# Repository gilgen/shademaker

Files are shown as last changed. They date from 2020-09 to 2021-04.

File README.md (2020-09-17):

# Shademaker

An open source implementation of a stepper driven automated blind system.

## Required components
* Stepper motor (5:1 planetary geared)
* Arduino
* Hacked CNC shield
* 8825 stepper drivers
* Light sensor module
* Up/Down momentary switches
* On/Off toggle switch
* Relay
* 24v solenoid
* 8mm shaft couplers (no more than 16mm in diameter)
* 8mm rod
* 24v power supply

## WIP
desk

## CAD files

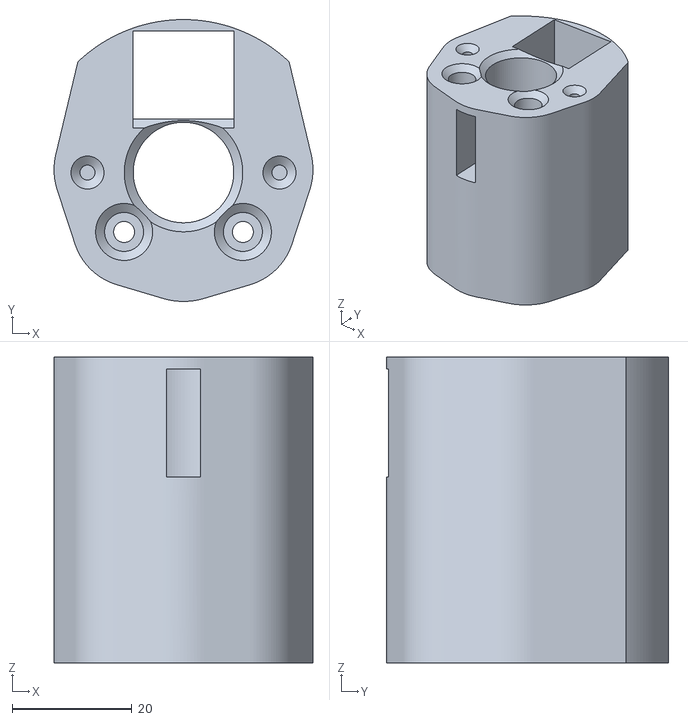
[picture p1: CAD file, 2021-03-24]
motor/stl/solenoid_holder.stl
43.2 x 47.0 x 51.0

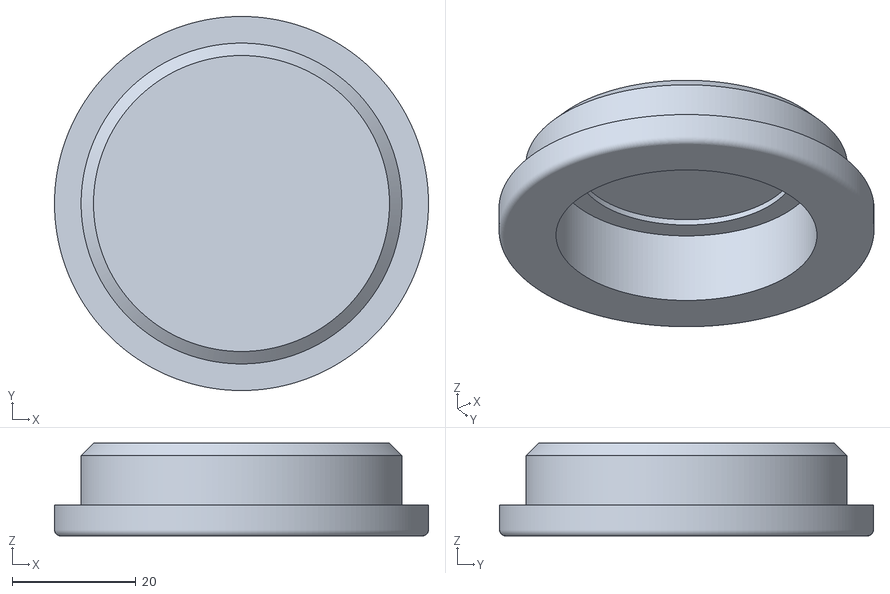
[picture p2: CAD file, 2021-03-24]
motor/stl/endcap.stl
60.3 x 60.3 x 15.0

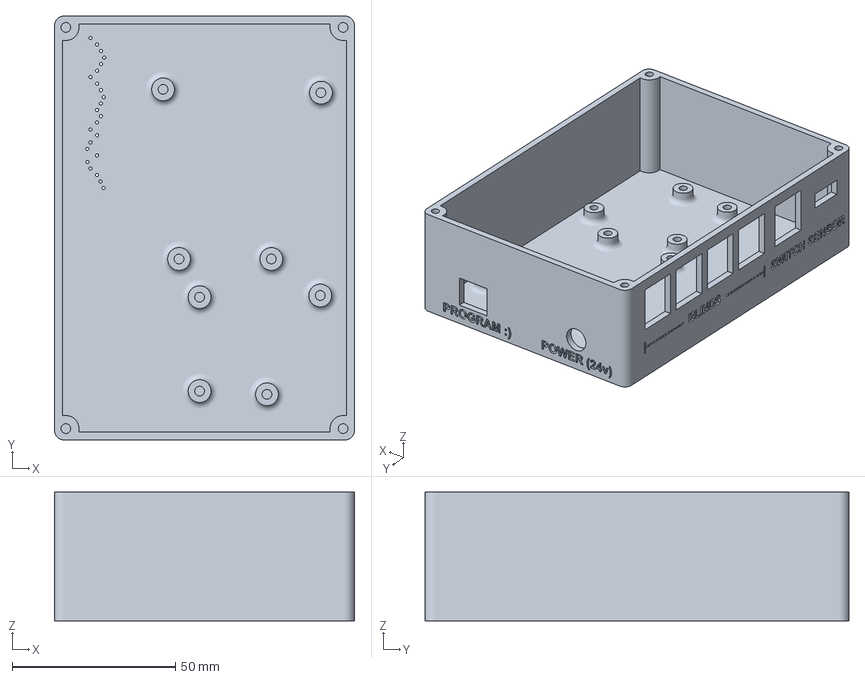
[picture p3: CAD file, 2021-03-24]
motor/stl/larger_enclosure_base.3mf
92.0 x 130.0 x 39.5 mm

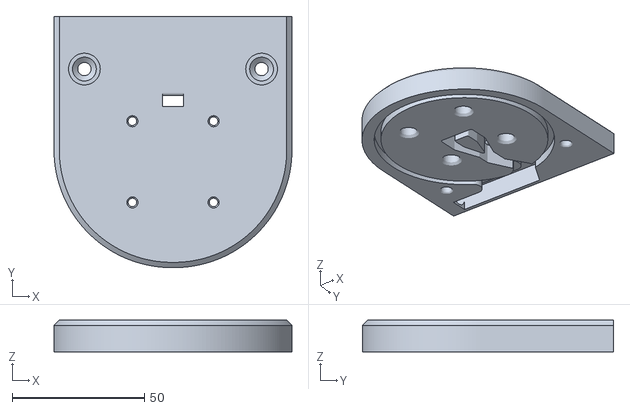
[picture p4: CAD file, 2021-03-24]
motor/stl/motor_mount.stl
90.0 x 95.0 x 12.0

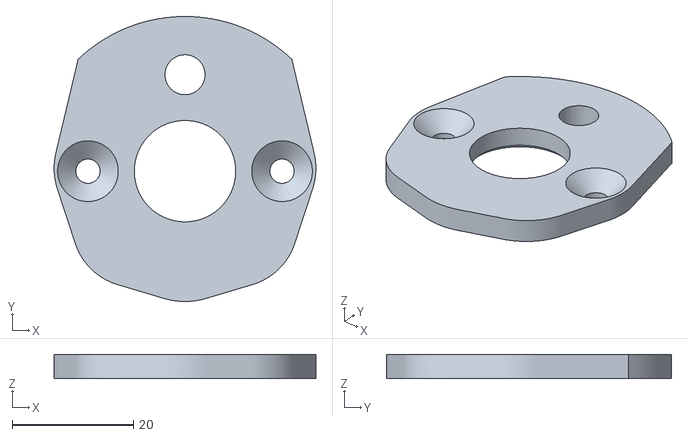
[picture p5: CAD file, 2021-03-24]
motor/stl/solenoid_plate.stl
43.2 x 47.0 x 4.00

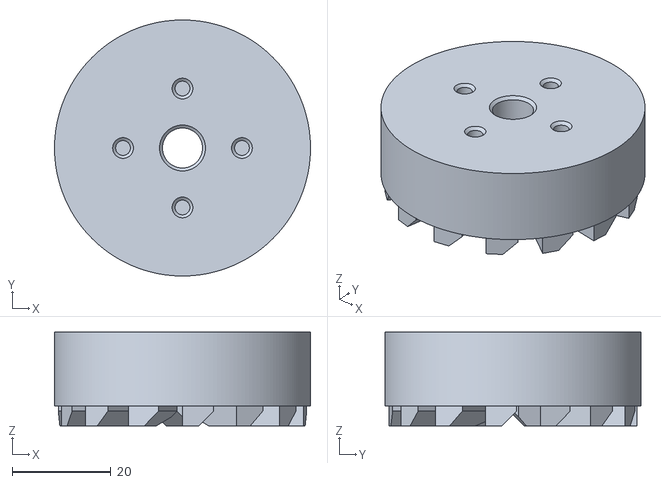
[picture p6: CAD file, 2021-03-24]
motor/stl/ratchet_gear.stl
51.9 x 51.9 x 19.0

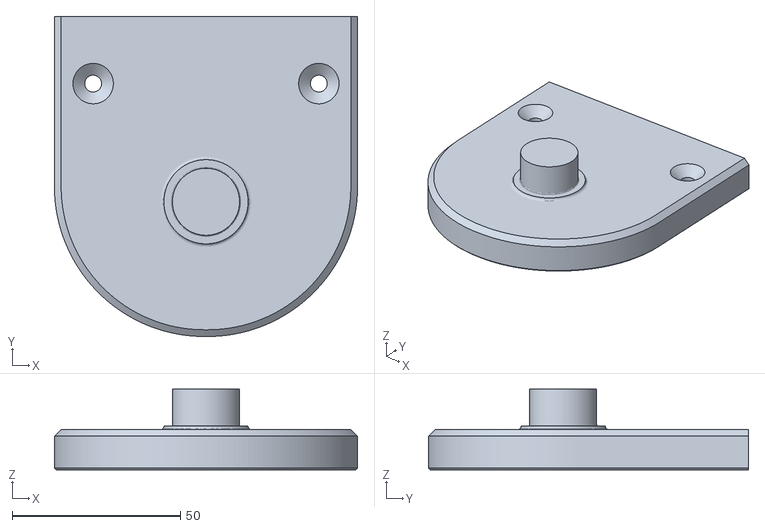
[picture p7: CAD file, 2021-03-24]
motor/stl/idler_mount.stl
90.0 x 95.0 x 24.0

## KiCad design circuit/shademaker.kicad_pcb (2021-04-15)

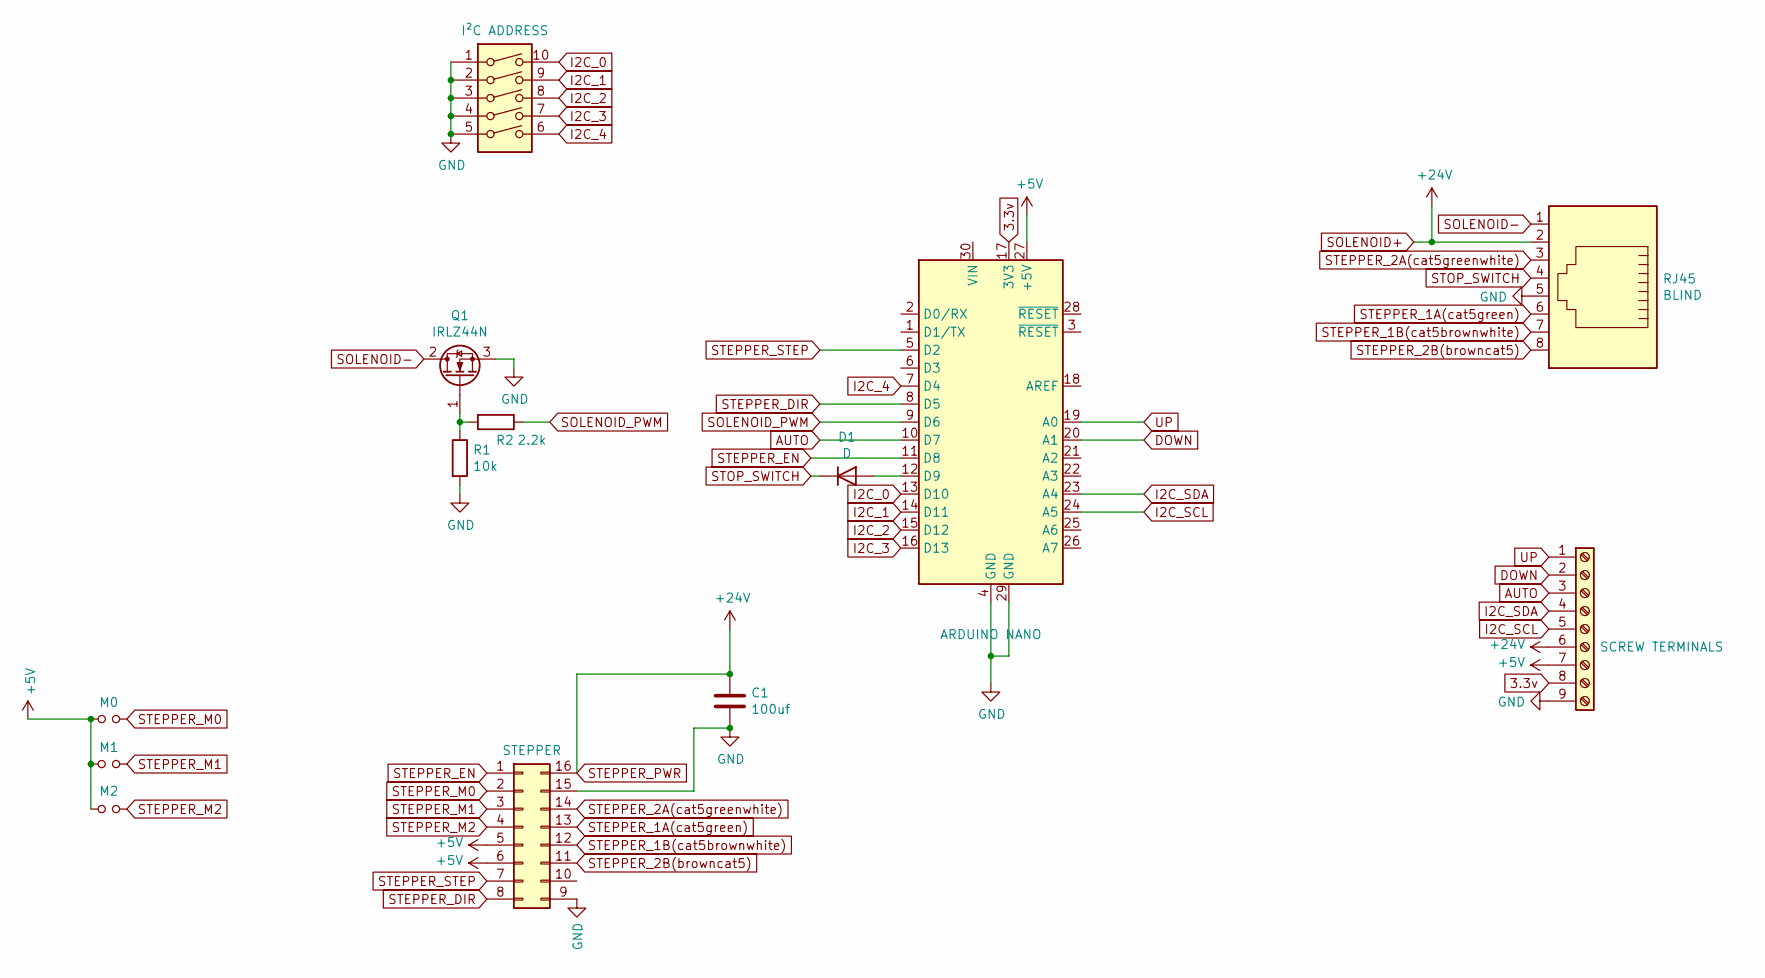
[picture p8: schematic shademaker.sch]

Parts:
ARDUINO1: ARDUINO NANO; Arduino_Nano
C1: 100uf; C_Radial_D10.0mm_H16.0mm_P5.00mm
D1: D; D_DO-15_P10.16mm_Horizontal
M1, M2: Jumper_NO_Small; TestPoint_2Pads_Pitch2.54mm_Drill0.8mm
MO1: M0; TestPoint_2Pads_Pitch2.54mm_Drill0.8mm
Q1: IRLZ44N; TO-220-3_Vertical
R1: 10k; R_Axial_DIN0207_L6.3mm_D2.5mm_P10.16mm_Horizontal
R2: 2.2k; R_Axial_DIN0207_L6.3mm_D2.5mm_P10.16mm_Horizontal
RJ45: BLIND; RJ45_Amphenol_54602-x08_Horizontal
SCREW1: SCREW TERMINALS; TerminalBlock_Phoenix_PT-1,5-9-3.5-H_1x09_P3.50mm_Horizontal
STEPPER1: STEPPER; Pololu_Breakout-16_15.2x20.3mm
SW1: I²C ADDRESS; SW_DIP_SPSTx05_Slide_6.7x14.26mm_W7.62mm_P2.54mm_LowProfile

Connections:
3.3v: ARDUINO1.17 (3V3), SCREW1.8
+5V: ARDUINO1.27 (+5V), M1.1, M2.1, MO1.1, SCREW1.7, STEPPER1.5, STEPPER1.6
AUTO: ARDUINO1.10 (D7), SCREW1.3
DOWN: ARDUINO1.20 (A1), SCREW1.2
GND: ARDUINO1.4 (GND), ARDUINO1.29 (GND), C1.2, Q1.3 (S), R1.2, RJ45.5, SCREW1.9, STEPPER1.9, STEPPER1.15, SW1.1, SW1.2, SW1.3, SW1.4, SW1.5
I2C_0: ARDUINO1.13 (D10), SW1.10
I2C_1: ARDUINO1.14 (D11), SW1.9
I2C_2: ARDUINO1.15 (D12), SW1.8
I2C_3: ARDUINO1.16 (D13), SW1.7
I2C_4: ARDUINO1.7 (D4), SW1.6
I2C_SCL: ARDUINO1.24 (A5), SCREW1.5
I2C_SDA: ARDUINO1.23 (A4), SCREW1.4
unnamed: ARDUINO1.12 (D9), D1.2 (A)
unnamed: Q1.1 (G), R1.1, R2.2
SOLENOID+: C1.1, RJ45.2, SCREW1.6, STEPPER1.16
SOLENOID-: Q1.2 (D), RJ45.1
SOLENOID_PWM: ARDUINO1.9 (D6), R2.1
STEPPER_1A(cat5green): RJ45.6, STEPPER1.13
STEPPER_1B(cat5brownwhite): RJ45.7, STEPPER1.12
STEPPER_2A(cat5greenwhite): RJ45.3, STEPPER1.14
STEPPER_2B(browncat5): RJ45.8, STEPPER1.11
STEPPER_DIR: ARDUINO1.8 (D5), STEPPER1.8
STEPPER_EN: ARDUINO1.11 (D8), STEPPER1.1
STEPPER_M0: MO1.2, STEPPER1.2
STEPPER_M1: M1.2, STEPPER1.3
STEPPER_M2: M2.2, STEPPER1.4
STEPPER_STEP: ARDUINO1.5 (D2), STEPPER1.7
STOP_SWITCH: D1.1 (K), RJ45.4
UP: ARDUINO1.19 (A0), SCREW1.1

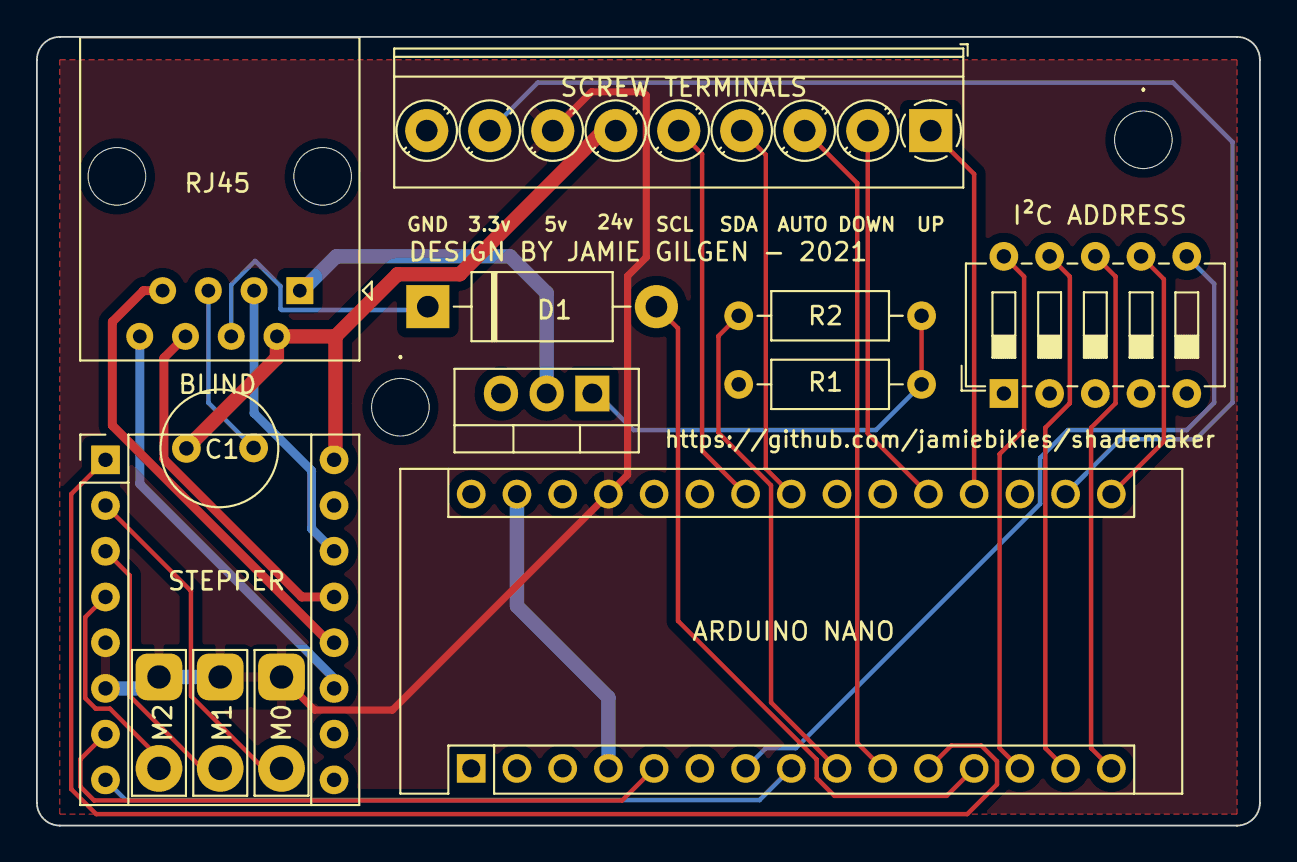
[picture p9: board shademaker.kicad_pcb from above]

Board: 2 copper layers, 67.9 x 43.8 mm, 15 parts (0 on the bottom side), 29 nets.

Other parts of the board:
., .#2: MountingHole_3.2mm_M3

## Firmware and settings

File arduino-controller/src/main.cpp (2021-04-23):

#include <AccelStepper.h>
#include <OneButton.h>
#include <Fsm.h>
#include <EEPROM.h>
#include <Wire.h>

// Forward declarations
boolean moveBlindsUpButtonActive();
boolean moveBlindsDownButtonActive();
boolean atTop();
boolean atBottom();
boolean autoModeEnabled();
boolean readyForAutoCmd();
boolean isBrightOutside();
boolean stopPinActive();
boolean atSetMidpointPosition();
boolean isValidCommand(int command);
int getI2CAddress();
void handleReceivedCommand();
long getDesiredBlindPosition();
void receiveI2CCommand(int numByets);
void i2cStateRequestHandler();
void setReceivedCommand(int command);
int getReceivedCommand();
void storeCurrentPositionAsBottom();
void setDesiredBlindPosition(long newPosition);
void homeStepper();
void moveBlinds(long longPosition);
void stopBlinds();
void initializeBottomPosition();
void initializePinIO();
void disableSolenoid();
void initializeSwitchHandlers();
void initializeStepper();
void initializeFSMTransitions();
void enableSolenoid();
void disableSolenoid();
void setCurrentPositionAsHome();
void setSolenoidLowPowerMode();
void runAutoModeRoutines();
void onStoppedStateEnter();
void onMovingStateEnter();
void onTransMovingToStoppedByMotorsAtTop();
void onTransStoppedToMovingByDownClick();
void onTransStoppedToMovingByUpClick();
void onTransStoppedToMovingByMoveToPosition();
void onTransMovingToMovingByMoveCommand();

#define DEBUG_MODE true

// Pin 0 not used
// Pin 1 not used
#define STEP_PIN    2
#define I2C_4       4
#define DIRECTION   5
#define SOLENOID    6
#define AUTO_MODE   7
#define ENABLE_PIN  8
#define STOP_PIN    9
#define I2C_0       10
#define I2C_1       11
#define I2C_2       12
#define I2C_3       13
#define UP_PIN      A0
#define DOWN_PIN    A1
#define TEMPERATURE A2
#define LIGHT       A3
#define I2C_SDA     A4
#define I2C_SCL     A5

// Stepper driver modules
#define DRV8825 0
#define TMC2209 1

// Should be one of the above driver modules
#define DRIVER_MODULE TMC2209

#if DRIVER_MODULE == DRV8825
  #define STEPS_PER_SHAFT_REVOLUTION 800L
  #define DIRECTION_PIN_INVERTED false
  #define STEP_PIN_INVERTED false
  #define ENABLE_PIN_INVERTED true
  #define SOLENOID_ENABLE_STEPPER_BUMP 250
#elif DRIVER_MODULE == TMC2209
  #define STEPS_PER_SHAFT_REVOLUTION 1600L
  #define DIRECTION_PIN_INVERTED true
  #define STEP_PIN_INVERTED false
  #define ENABLE_PIN_INVERTED true
  #define SOLENOID_ENABLE_STEPPER_BUMP 400
#else
  #error You need to select a DRIVER_MODULE
#endif

#define GEAR_RATIO 5.18181818L
#define AUTO_TRANSITION_INTERVAL (unsigned long)18000000 // 5 hours (or use 100000 for testing)
#define REVOLUTION (long)(STEPS_PER_SHAFT_REVOLUTION * GEAR_RATIO)
#define MAX_SPEED REVOLUTION * 0.4 // The UNO can do just over 4000 steps/s :'(
#define ACCELERATION MAX_SPEED * 1.8
#define SWITCHES_ACTIVE_LOW true
#define SWITCHES_USE_PULLUP true
#define BOTTOM_POSITION_ADDRESS 0
#define SLIP_CORRECTION 2 * REVOLUTION
#define SOLENOID_PWM_LEVEL 110
#define CYCLES_BEFORE_SOLENOID_LOW_POWER 30000L
#define HOMING_STATE_RETURN_VALUE 200

// I2C commands
#define STOP_COMMAND 101
#define DOWN_FOREVER_COMMAND 102
#define STORE_COMMAND 103
#define UP_FOREVER_COMMAND 104
#define FOREVER_POSITION 100*REVOLUTION
#define NOOP 200

// FSM events
#define AUTO_DOUBLE_CLICK   1
#define DOWN_CLICK          2
#define UP_CLICK            3
#define MOTORS_AT_TOP       5
#define STOP                6
#define MOVE_COMMAND        7

boolean isHoming = false;
unsigned long lastMoveAt = 0;
unsigned long startedAt;
long desiredBlindPosition;
long bottomPosition;
int loopCnt = 0;
int lastReceivedCommand = NOOP;

// Stepper
AccelStepper stepper = AccelStepper(AccelStepper::DRIVER, STEP_PIN, DIRECTION);

// Buttons
OneButton upSwitch = OneButton(UP_PIN, SWITCHES_ACTIVE_LOW, SWITCHES_USE_PULLUP);
OneButton downSwitch = OneButton(DOWN_PIN, SWITCHES_ACTIVE_LOW, SWITCHES_USE_PULLUP);
OneButton autoSwitch = OneButton(AUTO_MODE, SWITCHES_ACTIVE_LOW, SWITCHES_USE_PULLUP);

// FSM
State stoppedState(&onStoppedStateEnter, NULL, NULL);
State movingState(&onMovingStateEnter, NULL, NULL);
Fsm fsm(&stoppedState);

void setup() {
  Serial.begin(9600);
  Serial.print("Initializing\n");
  initializeBottomPosition();
  initializePinIO();
  disableSolenoid();  
  initializeStepper();
  Wire.begin(getI2CAddress());
  Wire.onReceive(receiveI2CCommand);
  Wire.onRequest(i2cStateRequestHandler);
  homeStepper();
  initializeSwitchHandlers();
  initializeFSMTransitions();
  fsm.run_machine();
  Serial.println("Done initialization");
  startedAt = millis();
}

void loop() {

  if (atTop() && getDesiredBlindPosition() <= 0) {
    fsm.trigger(MOTORS_AT_TOP);
  } else if (stepper.distanceToGo() == 0) {
    fsm.trigger(STOP);
  }

  handleReceivedCommand();

  // Only tick periodically to speed up the run loop. This
  // allows the motors to run a bit smoother
  // Uncomment if you're using a hardwired auto switch
  // if (loopCnt % 5000 == 0) {
  //   runAutoModeRoutines();
  // }

  if (loopCnt % 50 == 0) {
    // Tick the switches
    upSwitch.tick();
    downSwitch.tick();
    autoSwitch.tick();
  }

  // Run the steppers
  stepper.run();
  loopCnt++;
}

void initializePinIO() {
  pinMode(DIRECTION, OUTPUT);
  pinMode(STEP_PIN, OUTPUT);
  pinMode(STOP_PIN, INPUT_PULLUP);
  pinMode(ENABLE_PIN, OUTPUT);
  pinMode(SOLENOID, OUTPUT);
  pinMode(UP_PIN, INPUT_PULLUP);
  pinMode(DOWN_PIN, INPUT_PULLUP);
  pinMode(LIGHT, INPUT_PULLUP);
  pinMode(AUTO_MODE, INPUT_PULLUP);
  pinMode(I2C_0, INPUT_PULLUP);
  pinMode(I2C_1, INPUT_PULLUP);
  pinMode(I2C_2, INPUT_PULLUP);
  pinMode(I2C_3, INPUT_PULLUP);
  pinMode(I2C_4, INPUT_PULLUP);
}

void initializeFSMTransitions() {
  fsm.add_transition(&stoppedState, &movingState, DOWN_CLICK, &onTransStoppedToMovingByDownClick);
  fsm.add_transition(&stoppedState, &movingState, UP_CLICK, &onTransStoppedToMovingByUpClick);
  fsm.add_transition(&stoppedState, &movingState, MOVE_COMMAND, NULL);
  fsm.add_transition(&movingState, &movingState, MOVE_COMMAND, &onTransMovingToMovingByMoveCommand);
  fsm.add_transition(&movingState, &stoppedState, STOP, NULL);
  fsm.add_transition(&movingState, &stoppedState, DOWN_CLICK, NULL);
  fsm.add_transition(&movingState, &stoppedState, UP_CLICK, NULL);
  fsm.add_transition(&movingState, &stoppedState, MOTORS_AT_TOP, &onTransMovingToStoppedByMotorsAtTop);
}

// FSM transition events
void onStoppedStateEnter() {
  Serial.println("Stopped state enter");
  stopBlinds();
  setDesiredBlindPosition(stepper.currentPosition());
}

void onTransMovingToStoppedByMotorsAtTop() {
  Serial.println("Transition from moving up to stopped");
  stepper.stop();
  stepper.runToPosition();
  setCurrentPositionAsHome();
}

void onTransStoppedToMovingByUpClick() {
  setDesiredBlindPosition(0 - SLIP_CORRECTION);
}

void onTransStoppedToMovingByDownClick() {
  enableSolenoid();
  stepper.enableOutputs();
  stepper.runToNewPosition(stepper.currentPosition() - SOLENOID_ENABLE_STEPPER_BUMP);
  setDesiredBlindPosition(bottomPosition);
}

void onTransMovingToMovingByMoveCommand() {
  // Serial.println("In onTransMovingToMovingByMovingCommand");
  // if (stepper.currentPosition() > getDesiredBlindPosition()) {
  //   stepper.moveTo(getDesiredBlindPosition());
  // }
}

void onMovingStateEnter() {
  // Serial.println("in onMovingStateEnter");
  moveBlinds(getDesiredBlindPosition());
}

void moveBlinds(long newPosition) {
  // Serial.print("Moving blinds to: ");
  // Serial.println(newPosition);

  lastMoveAt = millis();
  enableSolenoid();
  stepper.enableOutputs();
  stepper.moveTo(newPosition);

  // Provide a natural bit of movement before putting the stepper into low power mode
  for(long i = 0; i < CYCLES_BEFORE_SOLENOID_LOW_POWER; i++) {
    stepper.run();
  }

  setSolenoidLowPowerMode();
}

void stopBlinds() {
  stepper.stop();
  stepper.runToPosition();
  disableSolenoid();
  stepper.disableOutputs();
}

void runAutoModeRoutines() {
  if (autoModeEnabled() && readyForAutoCmd()) {
    if (isBrightOutside()) {
      if (stepper.currentPosition() > 0) {
        Serial.println("It is bright outside. Moving blinds up");
        fsm.trigger(UP_CLICK);
      }
    } else {
      if (stepper.currentPosition() != bottomPosition) {
        Serial.println("It is dark outside. Moving blinds down.");
        fsm.trigger(DOWN_CLICK);
      }
    }
  }
}

boolean isValidCommand(int command) {
  return (command >= 0 && command <= 103) || command == NOOP;
}

void setReceivedCommand(int command) {
  lastReceivedCommand = command;
}

int getReceivedCommand() {
  return lastReceivedCommand;
}

void handleReceivedCommand() {
  int command = getReceivedCommand();
  if (command != NOOP) {
    if (command == STOP_COMMAND) {
      fsm.trigger(STOP);
    } else if (command == STORE_COMMAND) {
      storeCurrentPositionAsBottom();
    } else if (command == DOWN_FOREVER_COMMAND) {
      if (getDesiredBlindPosition() == FOREVER_POSITION) {
        fsm.trigger(STOP);
      } else {
        setDesiredBlindPosition(FOREVER_POSITION);
        fsm.trigger(MOVE_COMMAND);
      }
    } else if (command == UP_FOREVER_COMMAND) {
      if (getDesiredBlindPosition() == -1*FOREVER_POSITION) {
        fsm.trigger(STOP);
      } else {
        setDesiredBlindPosition(-1*FOREVER_POSITION);
        fsm.trigger(MOVE_COMMAND);
      }
    } else {
      long newPosition = bottomPosition * command / 100;
      if (newPosition == 0) {
        newPosition = (0 - SLIP_CORRECTION);
      }
      if (newPosition <= 0 && getDesiredBlindPosition() == 0) {
        // Don't action this command.
      } else if (newPosition != getDesiredBlindPosition()) {
        setDesiredBlindPosition(newPosition);
        fsm.trigger(MOVE_COMMAND);
      } else {
        fsm.trigger(STOP);
      }
    }
    setReceivedCommand(NOOP);
  }
}

void i2cStateRequestHandler() {
  // Serial.println("Received request for state");
  byte buffer[2];
  long massagedDesiredPosition, massagedSetPosition;

  if (isHoming) {
    massagedDesiredPosition = massagedSetPosition = HOMING_STATE_RETURN_VALUE;
  } else {
    massagedDesiredPosition = getDesiredBlindPosition();
    massagedSetPosition = stepper.currentPosition();
    if (massagedDesiredPosition < 0) {
      massagedDesiredPosition = 0;
    }
    if (massagedSetPosition < 0) {
      massagedSetPosition = 0;
    }
    massagedDesiredPosition = roundf(massagedDesiredPosition * 100.0 / bottomPosition);
    massagedSetPosition = roundf(massagedSetPosition * 100.0 / bottomPosition);
  }

  buffer[0] = massagedSetPosition;
  buffer[1] = massagedDesiredPosition;
  // Serial.println((String)"Sending: " + buffer[0] + " and " + buffer[1]);
  Wire.write(buffer, 2);
}

void receiveI2CCommand(int bytes) {
  int cmd;
  if (bytes != 1) {
    Serial.println((String)"Weird number of bytes!: " + bytes);
  }
  for (int i = 0; i < bytes; i++) {
    cmd = Wire.read(); // receive byte as a character
  }

  // int cmd = Wire.read();
  // Serial.print((String)"Bytes argument: " + bytes);
  if(isValidCommand(cmd)) {
    if (cmd != NOOP) {
      Serial.println((String)"Received I2C command: " + cmd);
    }
    setReceivedCommand(cmd);
  } else {
    Serial.print("Invalid command: ");
    Serial.println(cmd);
  }
}

// Just for testing out the command functionality
// void serialEvent() {
//   while(Serial.available()) {
//     int cmd = Serial.parseInt();
//     // Serial.println("Received command: " + cmd);
//     handleCommand(cmd);
//   }
// }

long getDesiredBlindPosition() {
  return desiredBlindPosition;
}

void setDesiredBlindPosition(long newDesiredPosition) {
  desiredBlindPosition = newDesiredPosition;
}

boolean readyForAutoCmd() {
  return ((millis() - lastMoveAt) > AUTO_TRANSITION_INTERVAL);
}

void disableAllSteppers() {
  stepper.disableOutputs();
}

void initializeSwitchHandlers() {
  downSwitch.attachClick([]() {
    if (!atBottom()) {
      fsm.trigger(DOWN_CLICK);
    }
  });

  upSwitch.attachClick([]() {
    if (!atTop()) {
      fsm.trigger(UP_CLICK);
    }
  });

  autoSwitch.attachDoubleClick([]() {
    Serial.println("Double click on auto switch.");
    long eepromBottomPosition;
    EEPROM.get(BOTTOM_POSITION_ADDRESS, eepromBottomPosition);
    if(bottomPosition == eepromBottomPosition) {
      Serial.println("Updated bottom position to 40 revolutions");
      bottomPosition = 40*REVOLUTION;
    } else {
      if (moveBlindsUpButtonActive() && moveBlindsDownButtonActive()) {
        bottomPosition = stepper.currentPosition();
        Serial.println("Found up and down buttons pressed. Storing stepper's current position as the bottom position: ");
        Serial.println(bottomPosition);
        storeCurrentPositionAsBottom();
      } else {
        bottomPosition = eepromBottomPosition;
        Serial.println("Didn't see up and down pressed so just resetting the bottom position to what is stored in EEPROM: ");
        Serial.println(bottomPosition);
      }
    }
  });

  autoSwitch.attachLongPressStart([]() {
    Serial.println("Auto mode engaged.");
    lastMoveAt = millis() - AUTO_TRANSITION_INTERVAL;
  });
}

void initializeStepper() {
  stepper.setEnablePin(ENABLE_PIN);
  stepper.setPinsInverted(DIRECTION_PIN_INVERTED, STEP_PIN_INVERTED, ENABLE_PIN_INVERTED);
  stepper.setMaxSpeed(MAX_SPEED);
  stepper.setAcceleration(ACCELERATION);
  stepper.disableOutputs();
}

void homeStepper() {
  Serial.println("in homeStepper");
  Serial.println("Homing...");
  isHoming = true;
  stepper.enableOutputs();
  enableSolenoid();
  stepper.moveTo(-5*REVOLUTION);
  long loopCnt = 0;
  while(!stopPinActive() && stepper.distanceToGo() != 0) {
    stepper.run();
    loopCnt++;
    if(loopCnt == CYCLES_BEFORE_SOLENOID_LOW_POWER) {
      setSolenoidLowPowerMode();
    }
  }
  stepper.stop();
  stepper.runToPosition();
  disableSolenoid();
  stepper.disableOutputs();
  if(!stopPinActive()) {
    Serial.println("Home switch isn't activated");
  } else {
    Serial.println("Stopped via home switch");
  }
  setCurrentPositionAsHome();
  isHoming = false;
  Serial.println("Set home position");
}

void initializeBottomPosition() {
  EEPROM.get(BOTTOM_POSITION_ADDRESS, bottomPosition);
  if (bottomPosition < 0) {
    Serial.println("Bottom position not configured. Defaulting to one revolution");
    bottomPosition = 1 * REVOLUTION;
  } else {
    Serial.print("Pulled bottom position from EEPROM: ");
    Serial.println(bottomPosition);
  }
}

void storeCurrentPositionAsBottom() {
  EEPROM.put(BOTTOM_POSITION_ADDRESS, stepper.currentPosition());
  bottomPosition = stepper.currentPosition();
}

void disableSolenoid() {
  digitalWrite(SOLENOID, LOW);
}

void enableSolenoid() {
  digitalWrite(SOLENOID, HIGH);
}

void setSolenoidLowPowerMode() {
  analogWrite(SOLENOID, SOLENOID_PWM_LEVEL);
}

void setCurrentPositionAsHome() {
  Serial.println("Set current position as home");
  stepper.setCurrentPosition(0);
}

boolean atBottom() {
  return stepper.currentPosition() == bottomPosition;
}

boolean stopPinActive() {
  return digitalRead(STOP_PIN) == LOW; 
}

boolean atTop() {
  return stopPinActive() || (stepper.distanceToGo() == 0 && stepper.targetPosition() <= 0);
}

boolean moveBlindsUpButtonActive() {
  return digitalRead(UP_PIN) == LOW;
}

boolean moveBlindsDownButtonActive() {
  return digitalRead(DOWN_PIN) == LOW;
}

boolean isBrightOutside() {
  return digitalRead(LIGHT) == LOW;
}

boolean autoModeEnabled() {
  return digitalRead(AUTO_MODE) == LOW;
}

int getI2CAddress() {
  Serial.print("Fetching I2C address...found: 0x");
  int address = 0;
  if (digitalRead(I2C_4) == LOW)
    address += 1;
  if (digitalRead(I2C_3) == LOW)
    address += 2;
  if (digitalRead(I2C_2) == LOW)
    address += 4;
  if (digitalRead(I2C_1) == LOW)
    address += 8;
  if (digitalRead(I2C_0) == LOW)
    address += 16;
  Serial.println(address, HEX);
  return(address);
}

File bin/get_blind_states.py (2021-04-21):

#!/usr/bin/env python

from smbus2 import SMBus
import sys
import os
import json
from blind_addresses import blind_address_mappings

I2C_NOOP = 200

# Since the only data that can be read is the set and current
# position, we don't have to send a command for the read block
# data. There's no differing address space we need to specify.

states = { "blindStates" : {}, "autoStates" : {} }

with SMBus(1) as bus:
    for num, addr in blind_address_mappings.items():
        states["blindStates"][num] = {}
        try:
            data = bus.read_i2c_block_data(addr, I2C_NOOP, 2)
            states["blindStates"][num]['cur'] = int(data[0])
            states["blindStates"][num]['set'] = int(data[1])
        except:
            states["blindStates"][num]['cur'] = 'unreachable'
            states["blindStates"][num]['set'] = 'unreachable'

with open(os.path.join(sys.path[0], '.auto-states')) as f:
  states["autoStates"] = json.load(f)

print json.dumps(states)

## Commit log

2021-03-24 Added model stls and 3mfs
    [Idle motor mount.3mf, Larger enclosure base.3mf, Mount enclosure (round).3mf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]
2021-03-29 PCB and circuit
    [shademaker-B_Cu.gbr, shademaker-B_Mask.gbr, shademaker-B_Paste.gbr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]
2021-03-29 Circuit + PCB
    [shademaker.kicad_pcb, shademaker.sch]
2021-04-15 Add platform.io setup to project
    [shademaker.kicad_pcb]
2021-04-15 Move things around
    [Larger enclosure base.3mf, end cap.stl, idler mount.stl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]
2021-04-15 Fix weird names on stl files
    [endcap.stl, idler_mount.stl, larger_enclosure_base.3mf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]
2021-04-15 Don't log to serial with an invalid command. Causes blips in motor movement
2021-04-15 Move circuit into root of project
    [shademaker-B_Cu.gbr, shademaker-B_Mask.gbr, shademaker-B_Paste.gbr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]
2021-04-16 Fix up the stats return when homing
    [main.cpp]
2021-04-21 Implement raspberry based auto control
2021-04-21 Update all auto sensors involved when a command is sent
2021-04-23 Use some better variable names in blind i2c command handlers
2021-04-23 Remove stop button functionality. It isn't necessary.
